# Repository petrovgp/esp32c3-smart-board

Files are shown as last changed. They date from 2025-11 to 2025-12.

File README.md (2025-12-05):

# ESP32-C3 Smart Board

A compact, battery-powered ESP32-C3 development board designed in **KiCad 9**, integrating power management, motion sensing, and display support in a small form factor. Ideal for low-power IoT or wearable applications.

## 🏢 Sponsor of today's project - PCBWay!

A huge thank you to PCBWay for sponsoring this project!

PCBWay provided high-quality PCB fabrication and assembly support, helping bring the hardware from prototype to reality. Their fast turnaround times, excellent communication, and reliable manufacturing made a big difference in the development process.

If you're looking for PCB manufacturing, assembly, CNC, or 3D-printing services, check out PCBWay **[here!](https://www.pcbway.com)**

Production files for this project were created using PCBWay KiCAD plugin and they can be used in PCBWay PCB and PCBA services right away!

Thanks again to PCBWay for supporting open-source hardware projects!

## 📸 Board design
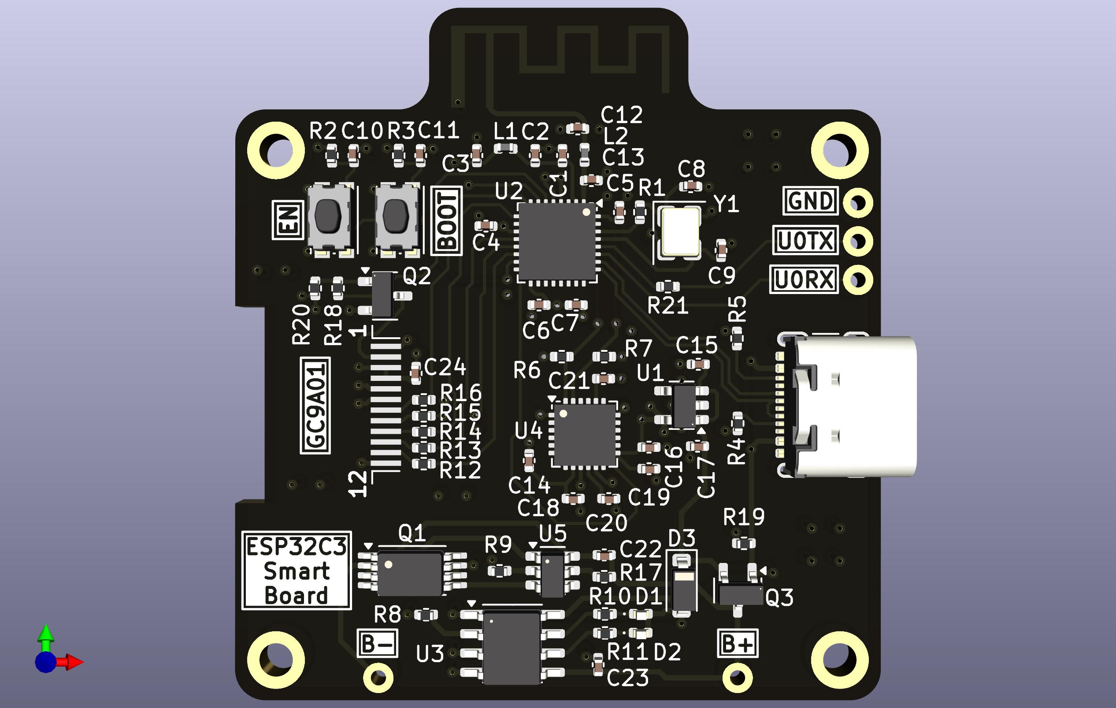
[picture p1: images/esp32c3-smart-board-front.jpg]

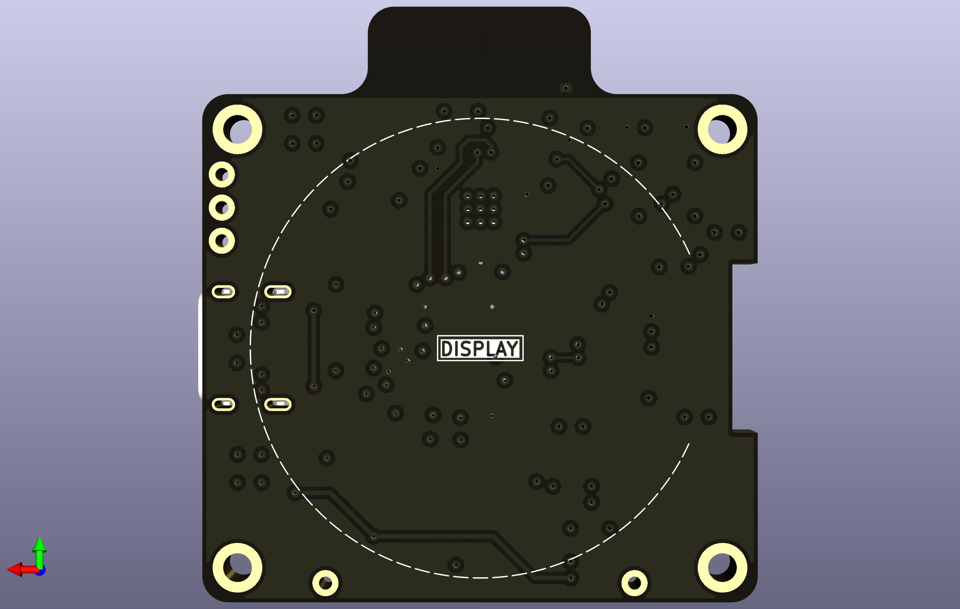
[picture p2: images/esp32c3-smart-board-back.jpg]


---

## 🧠 Features

### ⚡ Core
- **ESP32-C3** RISC-V microcontroller with Wi-Fi and BLE 5.0
- Compact **42 × 45 mm** PCB designed in KiCad 9
  - 4 layer stackup: L1 Signal | L2 Ground | L3 Ground | L4 Signal + Power
- Integrated **Inverted-F antenna** for stable wireless performance

### 🔋 Power System
- Operable from **Li-Ion / Li-Po battery** and **USB Type C**
- On-board **TP4056** linear charging IC
  - 250mA charging current configuration
- **DW01A + FS8205A** dual MOSFET battery protection circuit
- Power-sharing design — board can operate **while charging**
- **ME6211C** LDO regulator:
  - 500 mA max output current
  - 100 mV dropout at 100 mA

### 🧭 Sensors
- **MPU6050** 6-axis accelerometer and gyroscope  
  - Interrupt pin connected to ESP32-C3 for motion wake-up or gesture detection

### 🖥️ Display
- **GC9A01** round TFT display connector
  - 12-pin FPC interface for bare display module

### 🔌 Connectivity
- **USB Type-C** connector for power and programming
- Exposed UART pins for debugging

## 🧩 Production files
All design files were created in **KiCad 9** and production files have been exported with **PCBWay plugin** (available **[here](https://github.com/pcbway/PCBWay-Plug-in-for-Kicad.git)**):
- `schematics/` – full circuit schematics
- `kicad/` – KiCAD 9 project files
- `kicad/production/` – ready-to-manufacture files (GERBERs + BOM)

Adjustment of production files might be needed. Please check carefully before placing any manufacturing orders.

## 🧾 Revisions

| Revision | Manufactured | Notes | Available |
|---|---|---|---|
| **v1.0** | Nov 2025 | Improper GC9A01 footprint (wrong pitch), improper PMOS power sharing footprint (SOT23-5 instead of SOT23-3), everything else verified as OK  | Not available on Github
| **v1.1** | _Not manufactured_ | Updated GC9A01 footprint pitch, updated PMOS power sharing footprint, layout and silkscreen changes | Tagged v1.1 on Github
| **v1.2** | Dec 2025 | Layout and silkscreen changes | Tagged v1.2 on Github
| **v1.3** | _Not manufactured_ | Footprint changes, battery section layout changes, rounded antenna trace, bottom layer 3.3V plane addition, layout and silkscreen changes| Tagged v1.3 on Github

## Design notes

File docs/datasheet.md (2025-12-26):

# ESP32C3 Smart Board

**Product Name:** ESP32C3 Smart Board  
**Board Revision:** 1.3  
**Updated:** 26.12.2025  
**Author:** Marko Petrov (petrovgp)  

---

## 1. General Description

The ESP32C3 Smart board is a compact, battery-powered ESP32-based development board designed in **KiCad 9**, integrating power management, motion sensing, and display support in a small form factor. Ideal for low-power IoT or wearable applications.

---

## 2. Features

- ESP32 C3 MCU
    - ESP32C3FH4, RISC-V single-core 32-bit processor, up to 160 MHz
    - 4MB internal flash
    - 400KB SRAM
    - Wi-Fi 2.4 GHz IEEE 802.11 b/g/n
    - Bluetooth 5 (LE)
- ME6211A LDO regulator
    - 3.3V output voltage
    - 500mA max output current
    - 100mV @ 100mA dropout voltage
- Li-ion charging and protection ICs
    - TP4056 charging IC configured at 250mA
    - DW01A + FS8205A protection ICs
    - Power sharing circuit for use while charging
- MPU6050 accelerometer
    - Supports interrupt mode with INT pin
- GC9A01 display
    - 240x240 TFT color display
    - Supports up to 40MHz (40Mbps) on hardware SPI
- USB Type C connector
    - Power and programming interface for ESP32C3

---

## 3. Functional Block Diagram

```mermaid
flowchart LR
    %% =====================
    %% Power Path
    %% =====================
    subgraph Power["Power Path"]
        A[USB Type-C] -->|VBUS| B{Power Sharing Circuit}
        A --> C[TP4056 Li-Ion Charger]
        C -->|BAT| D[Li-Ion Battery]
        D -->|VBAT| B
        B -->|VCC| E[ME6211A LDO]
    end

    %% =====================
    %% Main System
    %% =====================
    subgraph System["System & Peripherals"]
        E -->|3V3| MCU[ESP32C3]
        E -->|3V3| DISP[GC9A01 Display]
        E -->|3V3| IMU[MPU6050 IMU]
    end

    %% =====================
    %% Data Interfaces
    %% =====================
    MCU <-->|I2C| IMU
    MCU <-->|SPI| DISP
```

---

## 4. Absolute Maximum Ratings

### Voltage ratings

| Parameter | Min | Typ | Max | Unit |
|---|-----|-----|-----|---|
| USB Type C voltage (VBUS) | 4.0 | 5.0 | 6.5 | V  |
| Battery voltage (VBAT) | -0.3| 3.6 | 4.2 | V  |
| High-level input voltage (VIH) | 2.5 |  -  | 3.6 | V  |
| Low-level input voltage (VIL)  | -0.3|  -  | 0.8 | V  |
| High-level output voltage (VOH)| 2.6 |  -  |  -  | V  |
| Low-level output voltage (VOL) |  -  |  -  | 0.33| V  |
| Ambient temperature | -40 | 25  | 125 |  °C  |

### Current ratings

| Parameter | Min | Typ | Max | Unit |
|---|-----|-----|-----|---|
| Input current (IBUS), w/ battery | 250 | 350 | 630 |  mA  |
| Input current (IBUS), no battery | 0.02| 100 | 380 |  mA  |
| Battery charing current |  -  | 250 |  -  |  mA  |

> Recommended operating conditions are the typical values

---

## 5. Pin configurations

```mermaid
graph LR
    %% Nodes
    MCU((Microcontroller))
    DISP["GC9A01 Display"]
    IMU["MPU6050 IMU"]
    UART["Exposed UART port"]
    USBC["USB Type C port"]

    %% Pins (subgraph style)
    subgraph MCU_PINS["MCU Pins"]
        MCU_GPIO0["GPIO0 / I2C_SDA"]
        MCU_GPIO1["GPIO1 / I2C_SCL"]
        MCU_GPIO4["GPIO4 / SPI_CLK"]
        MCU_GPIO6["GPIO6 / SPI_DATA"]
        MCU_GPIO7["GPIO7 / SPI_CS"]
        MCU_GPIO8["GPIO8 / RESET"]
        MCU_GPIO2["GPIO2 / BL"]
        MCU_GPIO3["GPIO3 / DC"]
        MCU_GPIO10["GPIO10 / MPU_INT"]
        MCU_GPIO18["GPIO18 / USB_D-"]
        MCU_GPIO19["GPIO19 / USB_D+"]
        MCU_GPIO20["GPIO20 / U0RX"]
        MCU_GPIO21["GPIO21 / U0TX"]
    end

    %% Connections
    MCU_GPIO0 --> |I2C_SDA| IMU
    MCU_GPIO1 --> |I2C_SCL| IMU
    MCU_GPIO10 --> |MPU_INT| IMU

    MCU_GPIO4 --> |SPI_CLK| DISP
    MCU_GPIO6 --> |SPI_MOSI| DISP
    MCU_GPIO7 --> |SPI_CS| DISP
    MCU_GPIO8 --> |RESET| DISP
    MCU_GPIO2 --> |PWM BL| DISP
    MCU_GPIO3 --> |DC| DISP

    MCU_GPIO18 --> |USB_D-| USBC
    MCU_GPIO19 --> |USB_D+| USBC

    MCU_GPIO20 --> |U0RX| UART
    MCU_GPIO21 --> |U0TX| UART

    %% Style
    classDef mcuPins fill:#FF0000,stroke:#333,stroke-width:2px;
    class MCU_GPIO0,MCU_GPIO1,MCU_XTALN,MCU_XTALP,MCU_GPIO4,MCU_GPIO6,MCU_GPIO7,MCU_GPIO8,MCU_GPIO2,MCU_GPIO3,MCU_GPIO10,MCU_GPIO18,MCU_GPIO19,MCU_GPIO20,MCU_GPIO21 mcuPins;
```
---

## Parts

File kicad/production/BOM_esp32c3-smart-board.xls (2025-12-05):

Designator | Quantity | Value | Footprint | Package | MPN | DNP | Mount_Type | Description | Sim.Pins | Sim.Device | Sim.Type
AE1 | 1 | Antenna_Shield | Texas_SWRA117D_2.4GHz_Right |  |  |  | tht | Antenna with extra pin for shielding
C1, C14, C16, C17, C23, C24, C7 | 7 | 10u | C_0402_1005Metric |  |  |  | smt | Unpolarized capacitor
C10, C11, C15, C18, C2, C20, C22, C3, C4, C5, C6 | 11 | 100n | C_0402_1005Metric |  |  |  | smt | Unpolarized capacitor
C12, C13 | 2 | 3.3p | C_0402_1005Metric |  |  |  | smt | Unpolarized capacitor
C19 | 1 | 10n | C_0402_1005Metric |  |  |  | smt | Unpolarized capacitor
C21 | 1 | 2.2n | C_0402_1005Metric |  |  |  | smt | Unpolarized capacitor
C8, C9 | 2 | 14p | C_0402_1005Metric |  |  |  | smt | Unpolarized capacitor
D1 | 1 | RED | LED_0402_1005Metric |  |  |  | smt | Light emitting diode | 1=K 2=A
D2 | 1 | GREEN | LED_0402_1005Metric |  |  |  | smt | Light emitting diode | 1=K 2=A
D3 | 1 | STPS0560Z | D_SOD-123 |  |  |  | smt | Schottky diode
J1 | 1 | USB_C_Receptacle_USB2.0_16P | USB_C_Receptacle_GCT_USB4105-xx-A_16P_TopMnt_Horizontal |  |  |  | smt | USB 2.0-only 16P Type-C Receptacle connector
J3 | 1 | Conn_01x12_Pin | GC9A01-12PIN-FPC |  |  |  | smt | Generic connector, single row, 01x12, script generated
L1 | 1 | 2n | L_0402_1005Metric |  |  |  | smt | Inductor
L2 | 1 | 2.2n | L_0402_1005Metric |  |  |  | smt | Inductor
Q1 | 1 | FS8205A | TSSOP-8_4.4x3mm_P0.65mm |  |  |  | smt
Q2 | 1 | BSS138 | SOT-23-3 |  |  |  | smt | 50V Vds, 0.22A Id, N-Channel MOSFET, SOT-23
Q3 | 1 | IRLML6401 | SOT-23-3 |  |  |  | smt | P-MOSFET transistor, drain/source/gate | 1=D 2=G 3=S | PMOS | VDMOS
R1 | 1 | 22R | R_0402_1005Metric |  |  |  | smt | Resistor
R10, R11, R12, R13, R14, R15, R16, R9 | 8 | 1k | R_0402_1005Metric |  |  |  | smt | Resistor
R17, R21 | 2 | 100R | R_0402_1005Metric |  |  |  | smt | Resistor
R18 | 1 | 10R | R_0402_1005Metric |  |  |  | smt | Resistor
R19, R2, R20, R3 | 4 | 10k | R_0402_1005Metric |  |  |  | smt | Resistor
R4, R5 | 2 | 5.1k | R_0402_1005Metric |  |  |  | smt | Resistor
R6, R7 | 2 | 4.7k | R_0402_1005Metric |  |  |  | smt | Resistor
R8 | 1 | 5k | R_0402_1005Metric |  |  |  | smt | Resistor
SW1, SW2 | 2 | SW_Push | SW_Push_1P1T_NO_CK_KMR2 |  |  |  | smt | Push button switch, generic, two pins
U1 | 1 | ME6211C33M5G | SOT-23-5 |  |  |  | smt
U2 | 1 | ESP32-C3 | QFN-32-1EP_5x5mm_P0.5mm_EP3.45x3.45mm_ThermalVias |  |  |  | smt | ESP32-C3 family is an ultra-low-power MCU-based SoC solution that supports 2.4 GHz Wi-Fi and Bluetooth®Low Energy (Bluetooth LE).
U3 | 1 | TP4056 | SOIC-8-1EP_3.9x4.9mm_P1.27mm_EP2.41x3.3mm_ThermalVias |  |  |  | smt | 1A Standalone Linear Li-ion/LiPo single-cell battery charger, 4.2V ±1% charge voltage, VCC = 4.0..8.0V, SOIC-8 (SOP-8)
U4 | 1 | MPU-6050 | InvenSense_QFN-24_4x4mm_P0.5mm |  |  |  | smt | InvenSense 6-Axis Motion Sensor, Gyroscope, Accelerometer, I2C
U5 | 1 | DW01A | SOT-23-6 |  |  |  | smt | Overcharge, overcurrent and overdischarge protection IC for single cell lithium-ion/polymer battery
Y1 | 1 | SJK-7U-40.000 | Crystal_SMD_3225-4Pin_3.2x2.5mm |  |  |  | smt | Four pin crystal, GND on pins 2 and 4

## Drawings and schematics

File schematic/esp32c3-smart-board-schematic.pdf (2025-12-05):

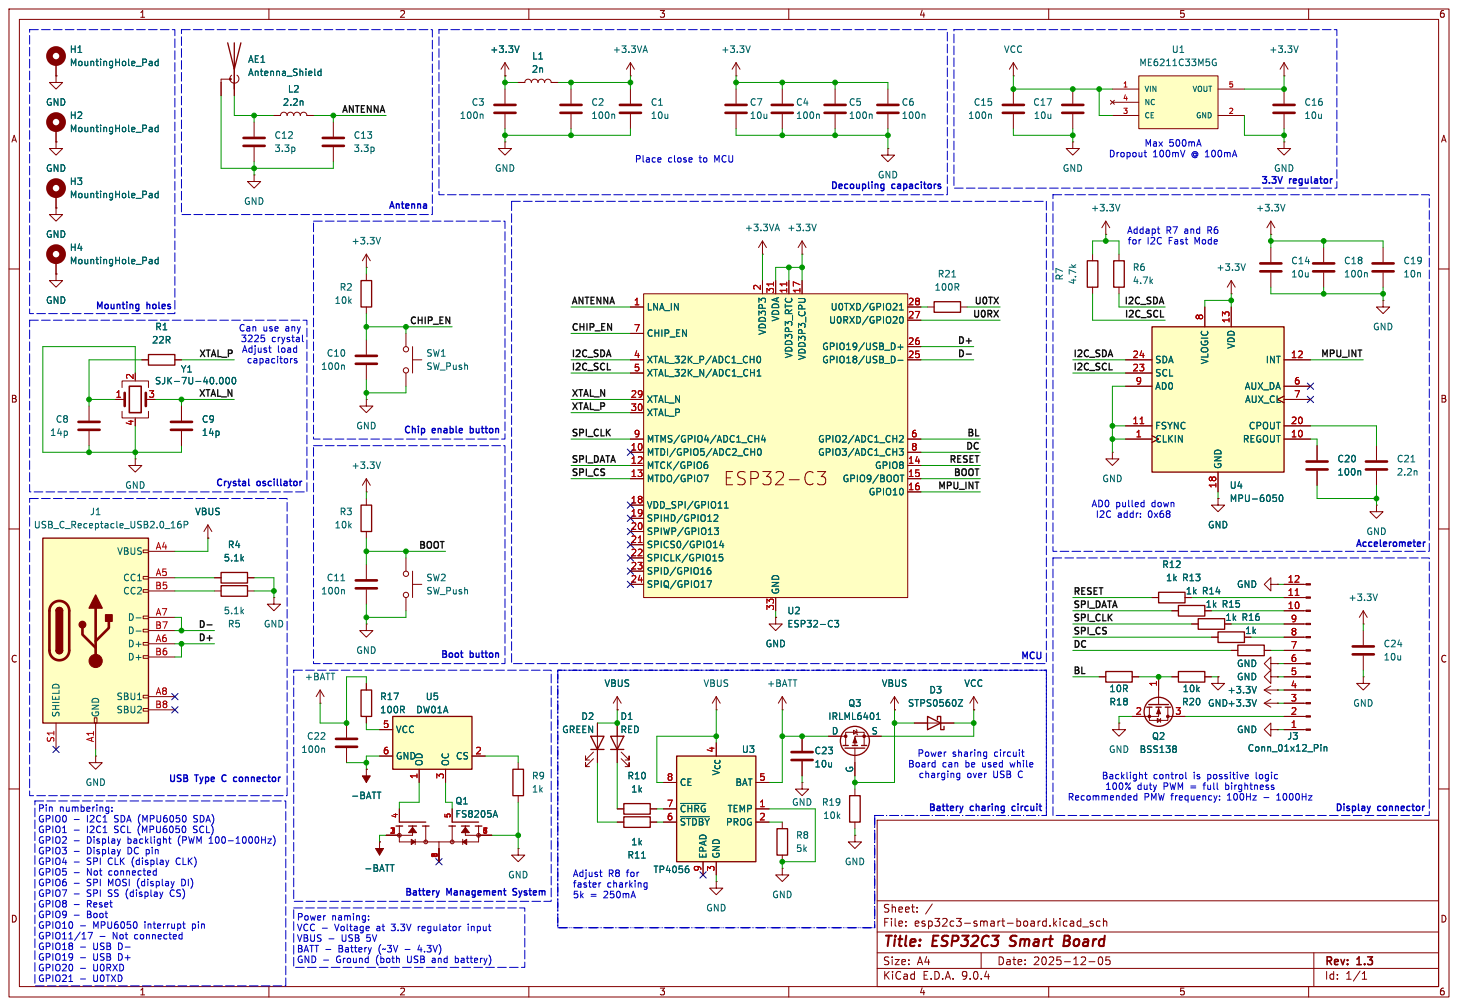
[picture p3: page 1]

Place close to MCU

3 BAT 5 TEMP 1 PROG 2 U3 TP4056 GND

Power sharing circuit Board can be used while

File: esp32c3-smart-board.kicad_sch Sheet: /
Id: 1/1 Title: ESP32C3 Smart Board

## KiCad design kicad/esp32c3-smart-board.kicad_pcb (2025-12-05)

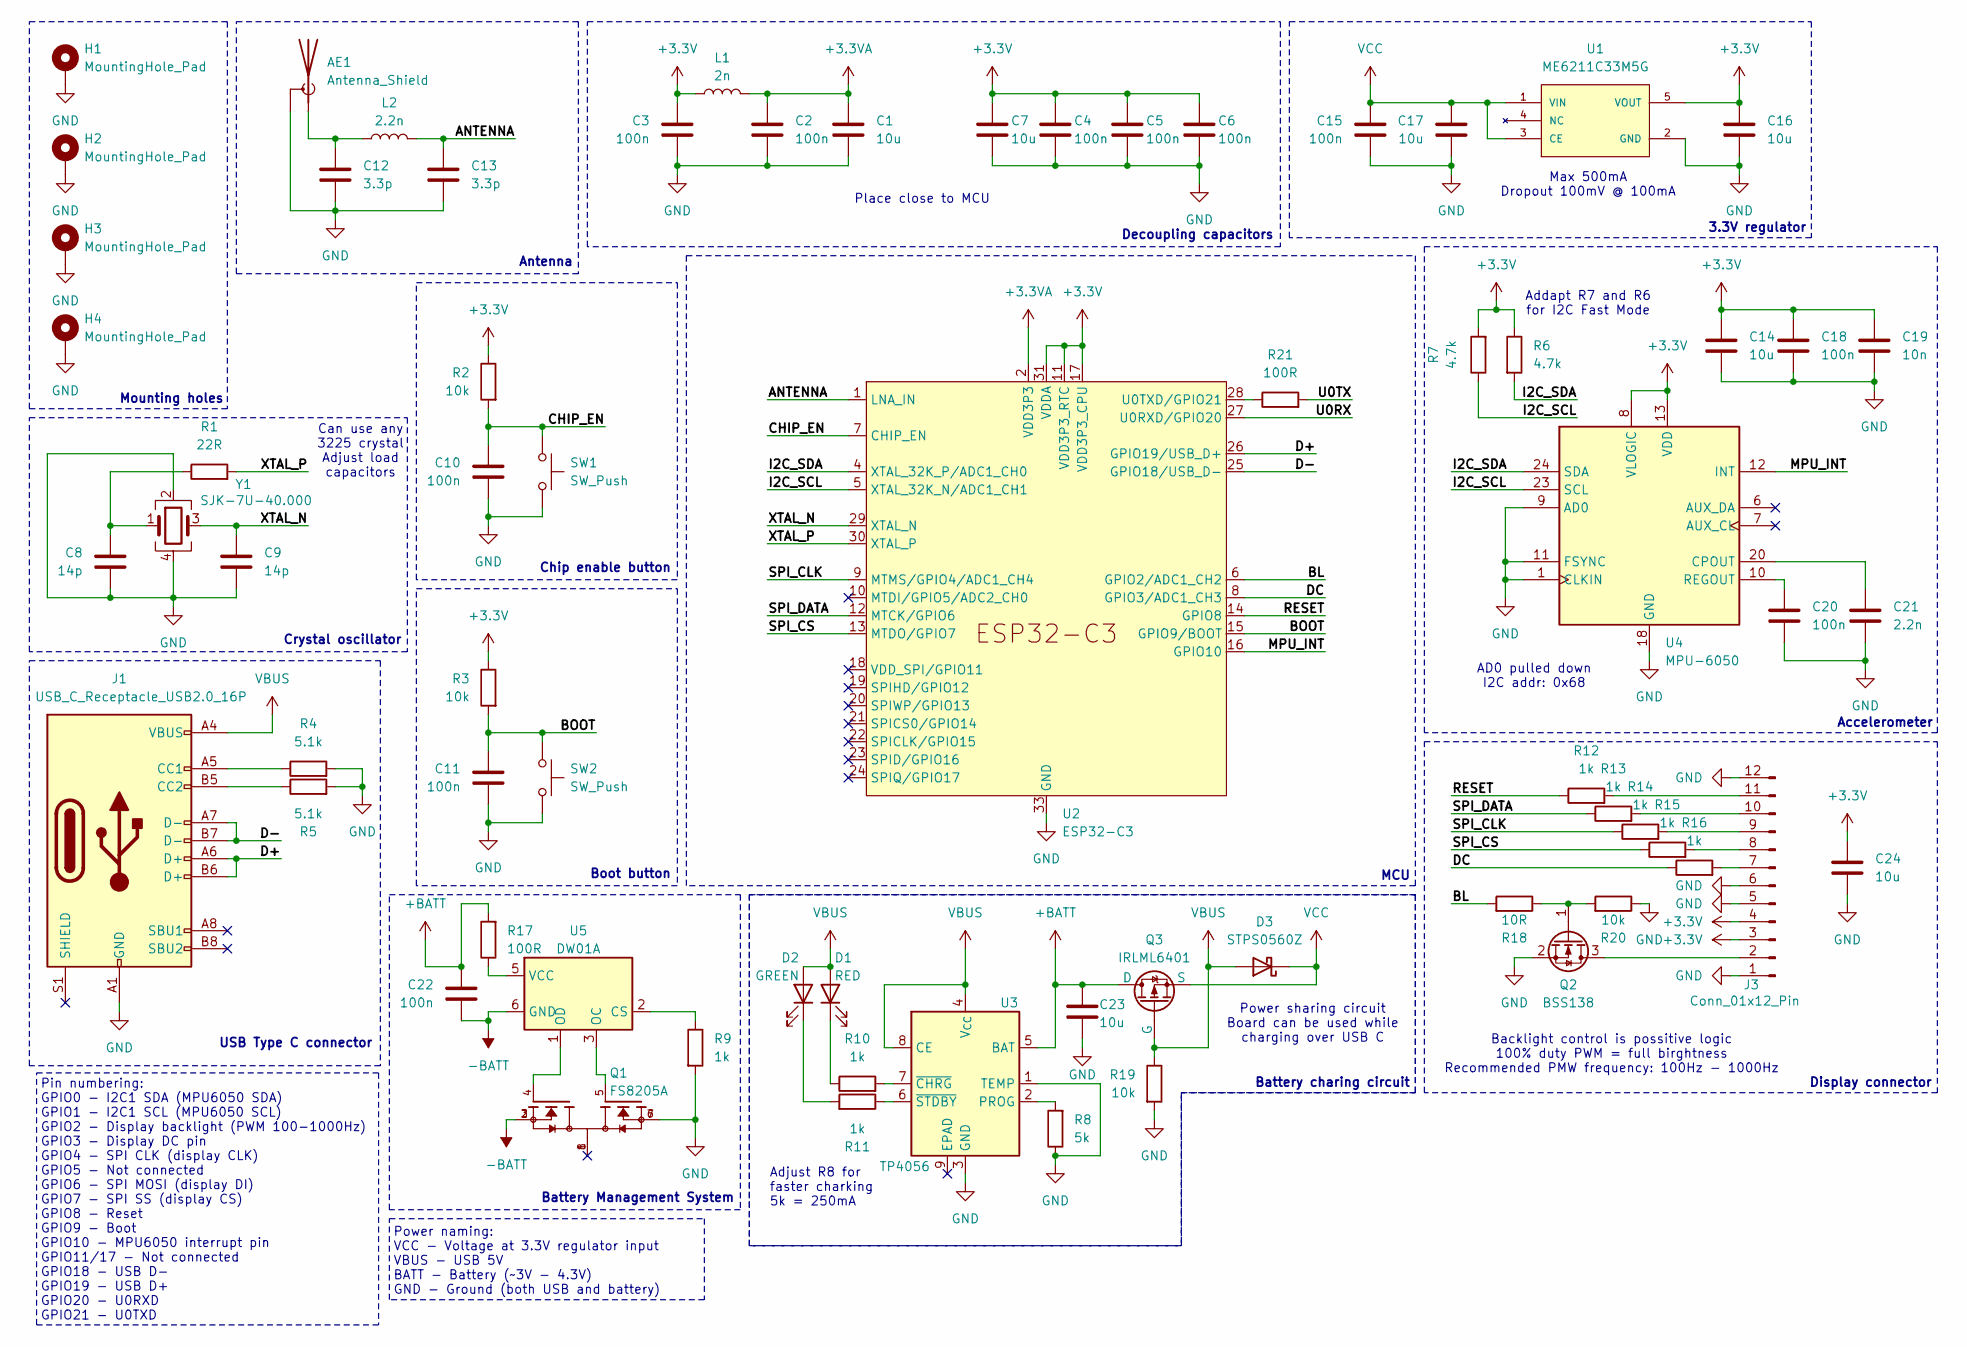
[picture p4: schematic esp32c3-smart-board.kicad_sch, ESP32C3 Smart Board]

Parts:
AE1: Antenna_Shield; Texas_SWRA117D_2.4GHz_Right
C1, C7, C14, C16, C17, C23, C24: 10u; C_0402_1005Metric
C2, C3, C4, C5, C6, C10, C11, C15, C18, C20, C22: 100n; C_0402_1005Metric
C8, C9: 14p; C_0402_1005Metric
C12, C13: 3.3p; C_0402_1005Metric
C19: 10n; C_0402_1005Metric
C21: 2.2n; C_0402_1005Metric
D1: RED; LED_0402_1005Metric
D2: GREEN; LED_0402_1005Metric
D3: STPS0560Z; D_SOD-123
H1, H2, H3, H4: MountingHole_Pad; MountingHole_2.2mm_M2_DIN965_Pad
J1: USB_C_Receptacle_USB2.0_16P; USB_C_Receptacle_GCT_USB4105-xx-A_16P_TopMnt_Horizontal
J3: Conn_01x12_Pin; GC9A01-12PIN-FPC
L1: 2n; L_0402_1005Metric
L2: 2.2n; L_0402_1005Metric
Q1: FS8205A; TSSOP-8_4.4x3mm_P0.65mm
Q2: BSS138; SOT-23-3
Q3: IRLML6401; SOT-23-3
R1: 22R; R_0402_1005Metric
R2, R3, R19, R20: 10k; R_0402_1005Metric
R4, R5: 5.1k; R_0402_1005Metric
R6, R7: 4.7k; R_0402_1005Metric
R8: 5k; R_0402_1005Metric
R9, R10, R11, R12, R13, R14, R15, R16: 1k; R_0402_1005Metric
R17, R21: 100R; R_0402_1005Metric
R18: 10R; R_0402_1005Metric
SW1, SW2: SW_Push; SW_Push_1P1T_NO_CK_KMR2
U1: ME6211C33M5G; SOT-23-5
U2: ESP32-C3; QFN-32-1EP_5x5mm_P0.5mm_EP3.45x3.45mm_ThermalVias
U3: TP4056; SOIC-8-1EP_3.9x4.9mm_P1.27mm_EP2.41x3.3mm_ThermalVias
U4: MPU-6050; InvenSense_QFN-24_4x4mm_P0.5mm
U5: DW01A; SOT-23-6
Y1: SJK-7U-40.000; Crystal_SMD_3225-4Pin_3.2x2.5mm

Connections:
+3.3V: C3.1, C4.1, C5.1, C6.1, C7.1, C14.1, C16.1, C18.1, C19.1, C24.1, J3.3, J3.4, L1.1, R2.1, R3.1, R6.1, R7.2, U1.5 (VOUT), U2.11 (VDD3P3_RTC), U2.17 (VDD3P3_CPU), U2.31 (VDDA), U2.32 (VDDA), U4.8 (VLOGIC), U4.13 (VDD)
+3.3VA: C1.1, C2.1, L1.2, U2.2 (VDD3P3), U2.3 (VDD3P3)
+BATT: C22.1, C23.1, Q3.1 (D), R17.2, U3.5 (BAT)
-BATT: C22.2, Q1.2, Q1.3, U5.6 (GND)
/ANTENNA: C13.1, L2.1, U2.1 (LNA_IN)
/BL: R18.2, U2.6 (GPIO2/ADC1_CH2)
/BOOT: C11.1, R3.2, SW2.1, U2.15 (GPIO9/BOOT)
/CHIP_EN: C10.1, R2.2, SW1.1, U2.7 (CHIP_EN)
/D+: J1.A6 (D+), J1.B6 (D+), U2.26 (GPIO19/USB_D+)
/D-: J1.A7 (D-), J1.B7 (D-), U2.25 (GPIO18/USB_D-)
/DC: R16.1, U2.8 (GPIO3/ADC1_CH3)
/I2C_SCL: R7.1, U2.5 (XTAL_32K_N/ADC1_CH1), U4.23 (SCL)
/I2C_SDA: R6.2, U2.4 (XTAL_32K_P/ADC1_CH0), U4.24 (SDA)
/MPU_INT: U2.16 (GPIO10), U4.12 (INT)
/RESET: R12.1, U2.14 (GPIO8)
/SPI_CLK: R14.1, U2.9 (MTMS/GPIO4/ADC1_CH4)
/SPI_CS: R15.1, U2.13 (MTDO/GPIO7)
/SPI_DATA: R13.1, U2.12 (MTCK/GPIO6)
/U0RX: U2.27 (U0RXD/GPIO20)
/U0TX: R21.2
/XTAL_N: C9.1, U2.29 (XTAL_N), Y1.3
/XTAL_P: R1.2, U2.30 (XTAL_P)
GND: AE1.2 (Shield), C1.2, C2.2, C3.2, C4.2, C5.2, C6.2, C7.2, C8.2, C9.2, C10.2, C11.2, C12.2, C13.2, C14.2, C15.2, C16.2, C17.2, C18.2, C19.2, C20.2, C21.2, C23.2, C24.2, H1.1, H2.1, H3.1, H4.1, J1.A1 (GND), J1.A12 (GND), J1.B1 (GND), J1.B12 (GND), J3.1, J3.5, J3.6, J3.12, Q1.6, Q1.7, Q2.2 (S), R4.2, R5.2, R8.1, R9.2, R19.2, R20.1, SW1.2, SW2.2, U1.2 (GND), U2.33 (GND), U3.1 (TEMP), U3.3 (GND), U4.1 (CLKIN), U4.9 (AD0), U4.11 (FSYNC), U4.18 (GND), Y1.2, Y1.4
unnamed: AE1.1 (A), C12.1, L2.2
unnamed: C8.1, R1.1, Y1.1
unnamed: D1.1 (K), R10.1
unnamed: D2.1 (K), R11.2
unnamed: J1.A5 (CC1), R4.1
unnamed: J1.B5 (CC2), R5.1
unnamed: J3.2, Q2.3 (D)
unnamed: J3.7, R16.2
unnamed: J3.8, R15.2
unnamed: J3.9, R14.2
unnamed: J3.10, R13.2
unnamed: J3.11, R12.2
unnamed: Q2.1 (G), R18.1, R20.2
unnamed: R21.1, U2.28 (U0TXD/GPIO21)
unnamed: R8.2, U3.2 (PROG)
unnamed: R10.2, U3.7 (~CHRG)
unnamed: R11.1, U3.6 (~STDBY)
unnamed: C21.1, U4.20 (CPOUT)
unnamed: C20.1, U4.10 (REGOUT)
unnamed: R9.1, U5.2 (CS)
unnamed: Q1.5, U5.3 (OC)
unnamed: Q1.4, U5.1 (OD)
unnamed: R17.1, U5.5 (VCC)
VBUS: D1.2 (A), D2.2 (A), D3.2 (A), J1.A4 (VBUS), J1.A9 (VBUS), J1.B4 (VBUS), J1.B9 (VBUS), Q3.2 (G), R19.1, U3.4 (V_{CC}), U3.8 (CE)
VCC: C15.1, C17.1, D3.1 (K), Q3.3 (S), U1.1 (VIN), U1.3 (CE)

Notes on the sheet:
Display connector
Antenna
Chip enable button
Addapt R7 and R6 for I2C Fast Mode
Decoupling capacitors
Can use any 3225 crystal Adjust load capacitors
Mounting holes
Battery charing circuit
USB Type C connector
Battery Management System
Adjust R8 for faster charking 5k = 250mA
Power sharing circuit Board can be used while charging over USB C
Max 500mA Dropout 100mV @ 100mA
Accelerometer
Place close to MCU
AD0 pulled down I2C addr: 0x68
Pin numbering: GPIO0 - I2C1 SDA (MPU6050 SDA) GPIO1 - I2C1 SCL (MPU6050 SCL) GPIO2 - Display backlight (PWM 100-1000Hz) GPIO3 - Display DC pin GPIO4 - SPI CLK (display CLK) GPIO5 - Not connected GPIO6 - SPI MOSI (display DI) GPIO7 - SPI SS (display CS) GPIO8 - Reset GPIO9 - Boot GPIO10 - MPU6050 in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
Boot button
Power naming: VCC - Voltage at 3.3V regulator input VBUS - USB 5V BATT - Battery (~3V - 4.3V) GND - Ground (both USB and battery)
Crystal oscillator
MCU
3.3V regulator
Backlight control is possitive logic 100% duty PWM = full birghtness Recommended PMW frequency: 100Hz - 1000Hz

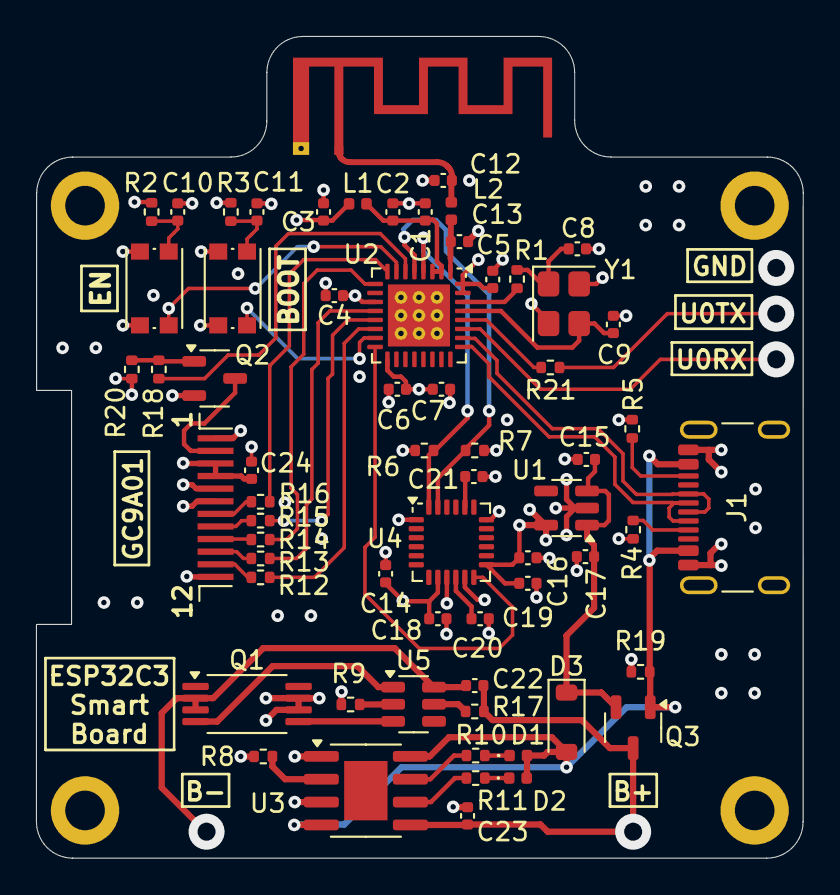
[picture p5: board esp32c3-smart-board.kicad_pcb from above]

Board: 4 copper layers, 42.6 x 45.7 mm, 68 parts (0 on the bottom side), 46 nets.

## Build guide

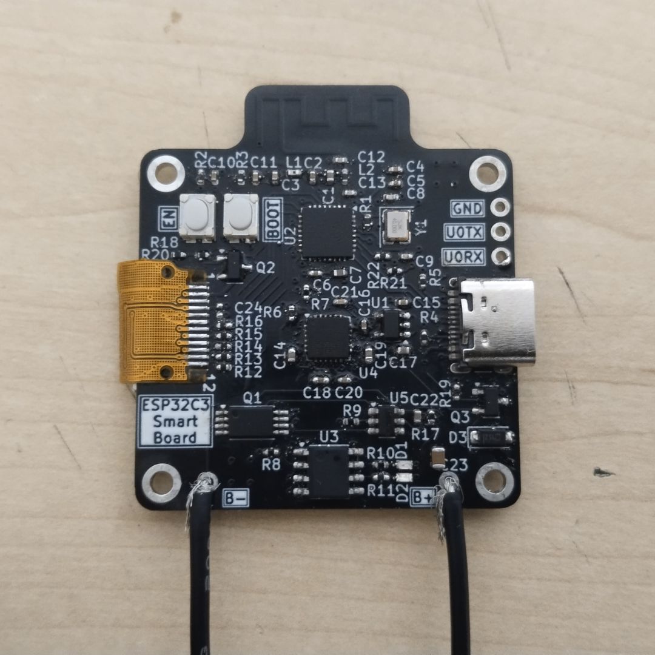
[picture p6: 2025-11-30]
images/manufactures-rev1.2-front.jpg

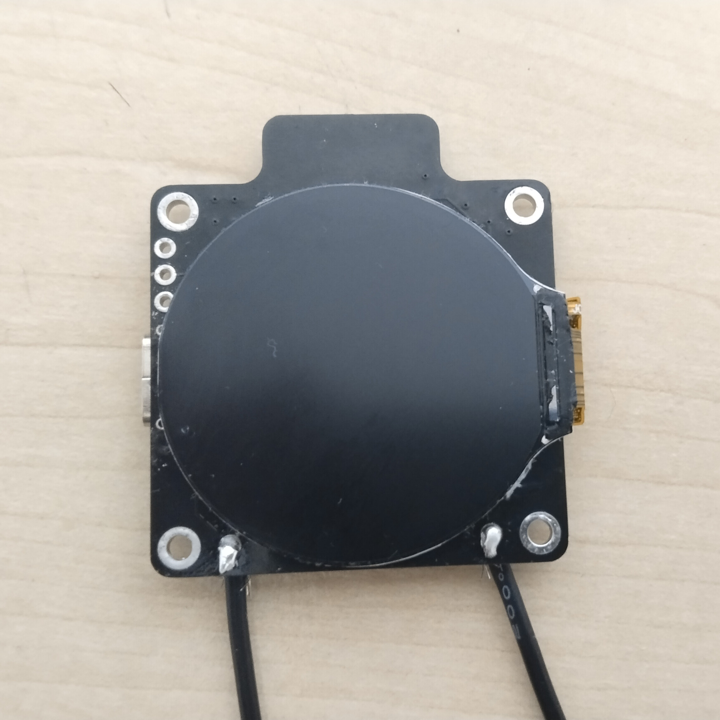
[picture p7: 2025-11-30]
images/manufactured-rev1.2-back.jpg

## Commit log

2025-11-09 Add schematic
2025-11-09 Add KiCAD 9 project and production files
    [BOM_esp32c3-smart-board.xls, esp32c3-smart-board.kicad_pcb, esp32c3-smart-board.kicad_sch]
2025-11-09 Add board design images
2025-11-16 Update KiCAD project files
    [esp32c3-smart-board.kicad_pcb]
2025-11-16 Update board design images
2025-11-30 Update images from manufactured board
2025-12-05 Update KiCAD project for revision 1.3
    [esp32c3-smart-board.kicad_pcb, esp32c3-smart-board.kicad_sch]
2025-12-05 Update production files for revision 1.3
    [BOM_esp32c3-smart-board.xls]
2025-12-05 Update board design images for revision 1.3
2025-12-05 Update board schematic for revision 1.3
2025-12-05 Add board layer stackup to README.md
